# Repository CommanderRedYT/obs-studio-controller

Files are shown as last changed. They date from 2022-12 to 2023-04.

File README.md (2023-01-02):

# obs-studio-controller
DIY hardware + software to control obs studio

## What is this?
This project will be a do-it-yourself solution to control OBS Studio.

It will have a custom PCB, based on the ESP32, with rotary encoders, buttons and and optional tft display.
I am planning on having a NodeJS backend as there are already great librarys to connect to OBS Studio!
The backend will also host a website to configure the device.

I am also planning on making a Video series showing my path on creating this project.

Tl;Dr:

## Features

- [ ] Custom PCB containing digital and analog inputs, based on the Espressif 32 Microcontroller.
- [ ] A 3D printable housing for the electronics
- [ ] NodeJS backend for configuring or updating the device

More will be added after designing and testing!

## Updating
I am planning to implement Over The Air Updates as well as flashing via USB C.

The ESP32 software will be using the ESP-IDF. From experience I have noticed some usability problems, so I will be using GitHub CI to build and then host the binaries.

## Contributing
If you encounter any problems, or have improvements, feel free to open an Issue or even a Pull Request!

## "Roadmap"
- After ordering the [first version](https://github.com/CommanderRedYT/obs-studio-controller/releases/tag/ordered-01) I discovered that I accidentally selected the wrong part for the rotary encoders (ones without buttons). Next revision will have that fixed, but for now, I will need to reorder the right components and try to replace the ones on the pcb

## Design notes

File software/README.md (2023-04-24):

# Software

## Compiling the firmware
1. Make sure you fully clone this repository with `git clone --recursive git@github.com:CommanderRedYT/obs-studio-controller.git`
2. Install the esp-idf via `./esp-idf/install.sh`
3. Source the environment via `source ./export.sh` or `. .export.sh`
4. Switch to the correct build config via `switchconf.sh <config>`
5. Run `idf.py build` to build the firmware

## Information for Flashing
Because the display is connected to GPIO12, you will need to burn an efuse to set the flash voltage to 3.3V. To do this, execute `tools/dev-burn-efuse` and enter `BURN`.

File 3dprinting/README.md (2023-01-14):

# 3d printing

This is a collection of 3d printing files for the project.

## File structure
There is a folder for each tagged version of the pcb (if it is not compatible anymore). In there, there are files named **&lt;name&gt;_&lt;fusion360_version&gt;.stl**.

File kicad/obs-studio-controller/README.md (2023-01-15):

# pcb

## Version 0.1 (Routing complete)
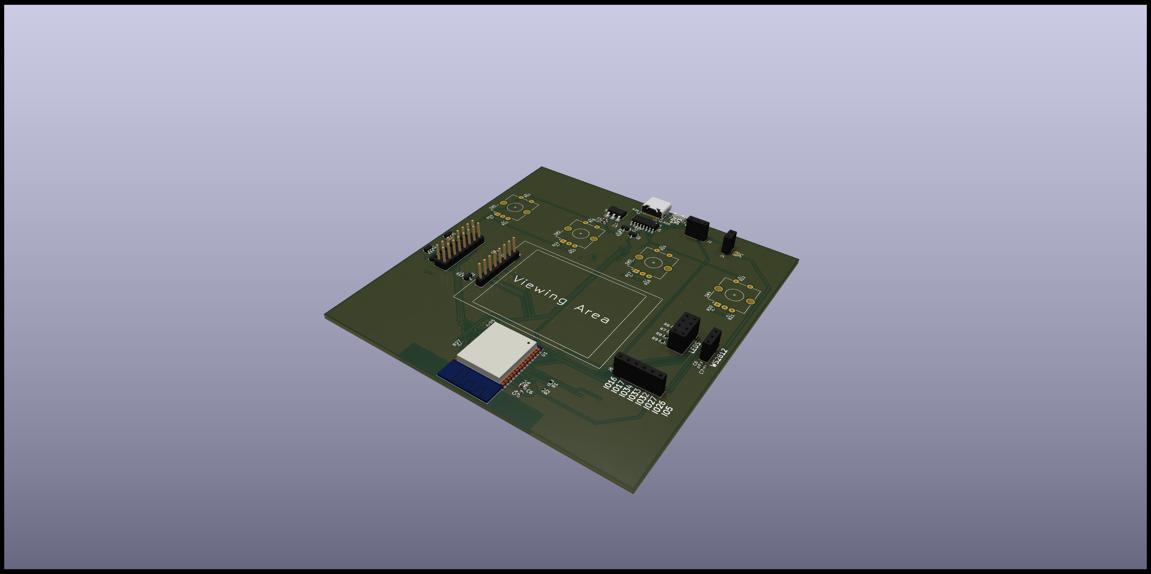
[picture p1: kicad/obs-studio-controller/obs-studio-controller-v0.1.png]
Image of version 0.1


## Version 1.0 (PCB complete)
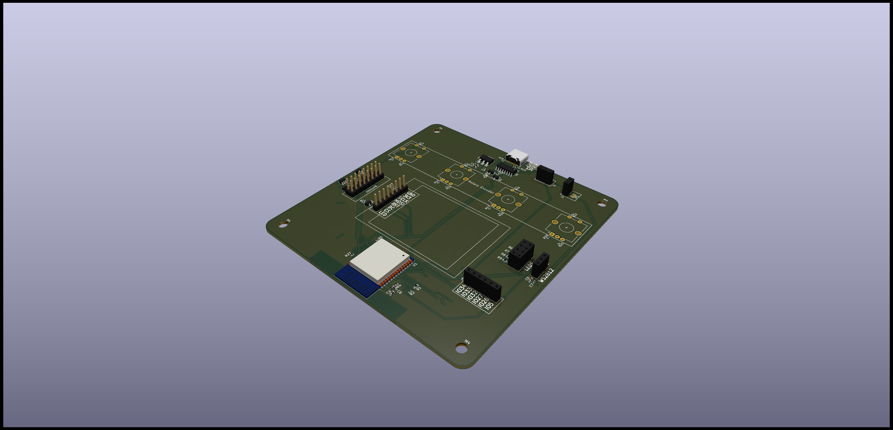
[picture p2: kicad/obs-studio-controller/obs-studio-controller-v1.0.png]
Image of version 1.0


## Version 1.1 (Fix wrong rotary encoder)
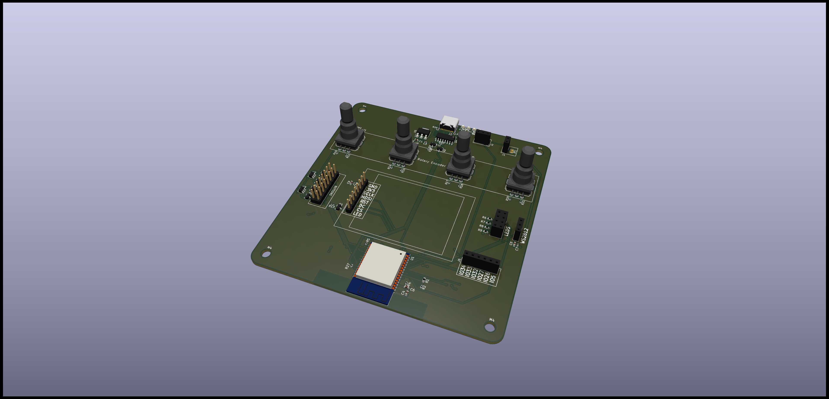
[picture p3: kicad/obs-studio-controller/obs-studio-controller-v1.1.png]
Image of version 1.1


## Version 1.2 (Fix flipped display header)
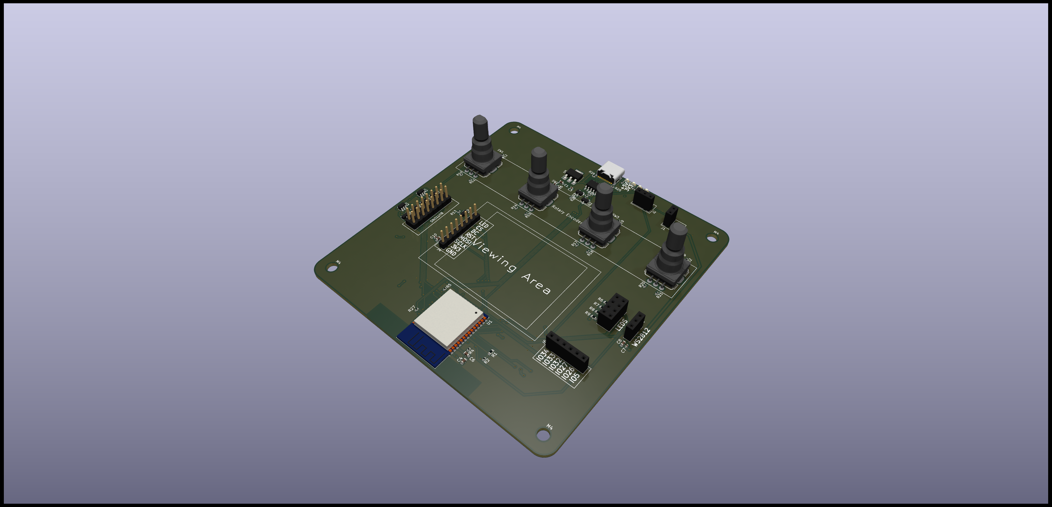
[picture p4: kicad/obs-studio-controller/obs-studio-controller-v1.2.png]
Image of version 1.2


## Version 2.0 (Actually connect the rotary encoders)
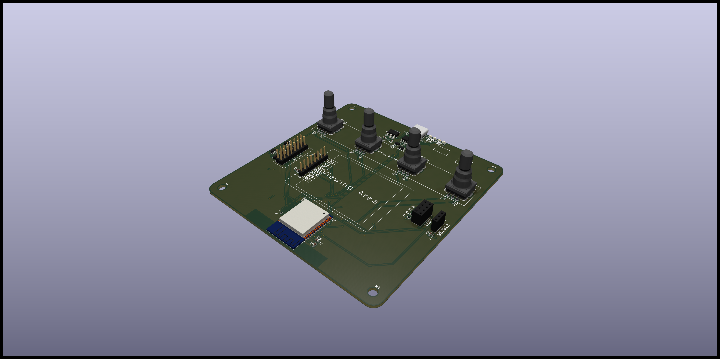
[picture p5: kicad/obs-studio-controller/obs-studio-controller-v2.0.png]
Image of version 2.0


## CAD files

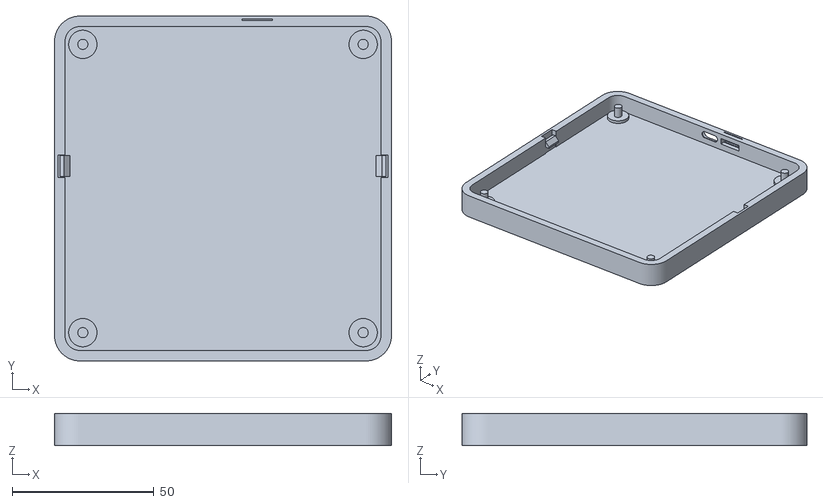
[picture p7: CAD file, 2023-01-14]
3dprinting/v1.1/case_bottom_v8.stl
119.0 x 121.8 x 11.4

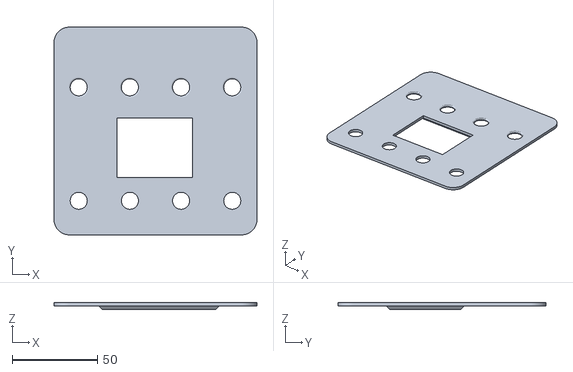
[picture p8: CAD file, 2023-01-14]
3dprinting/v1.1/case_top_v8.stl
119.0 x 121.8 x 4.00

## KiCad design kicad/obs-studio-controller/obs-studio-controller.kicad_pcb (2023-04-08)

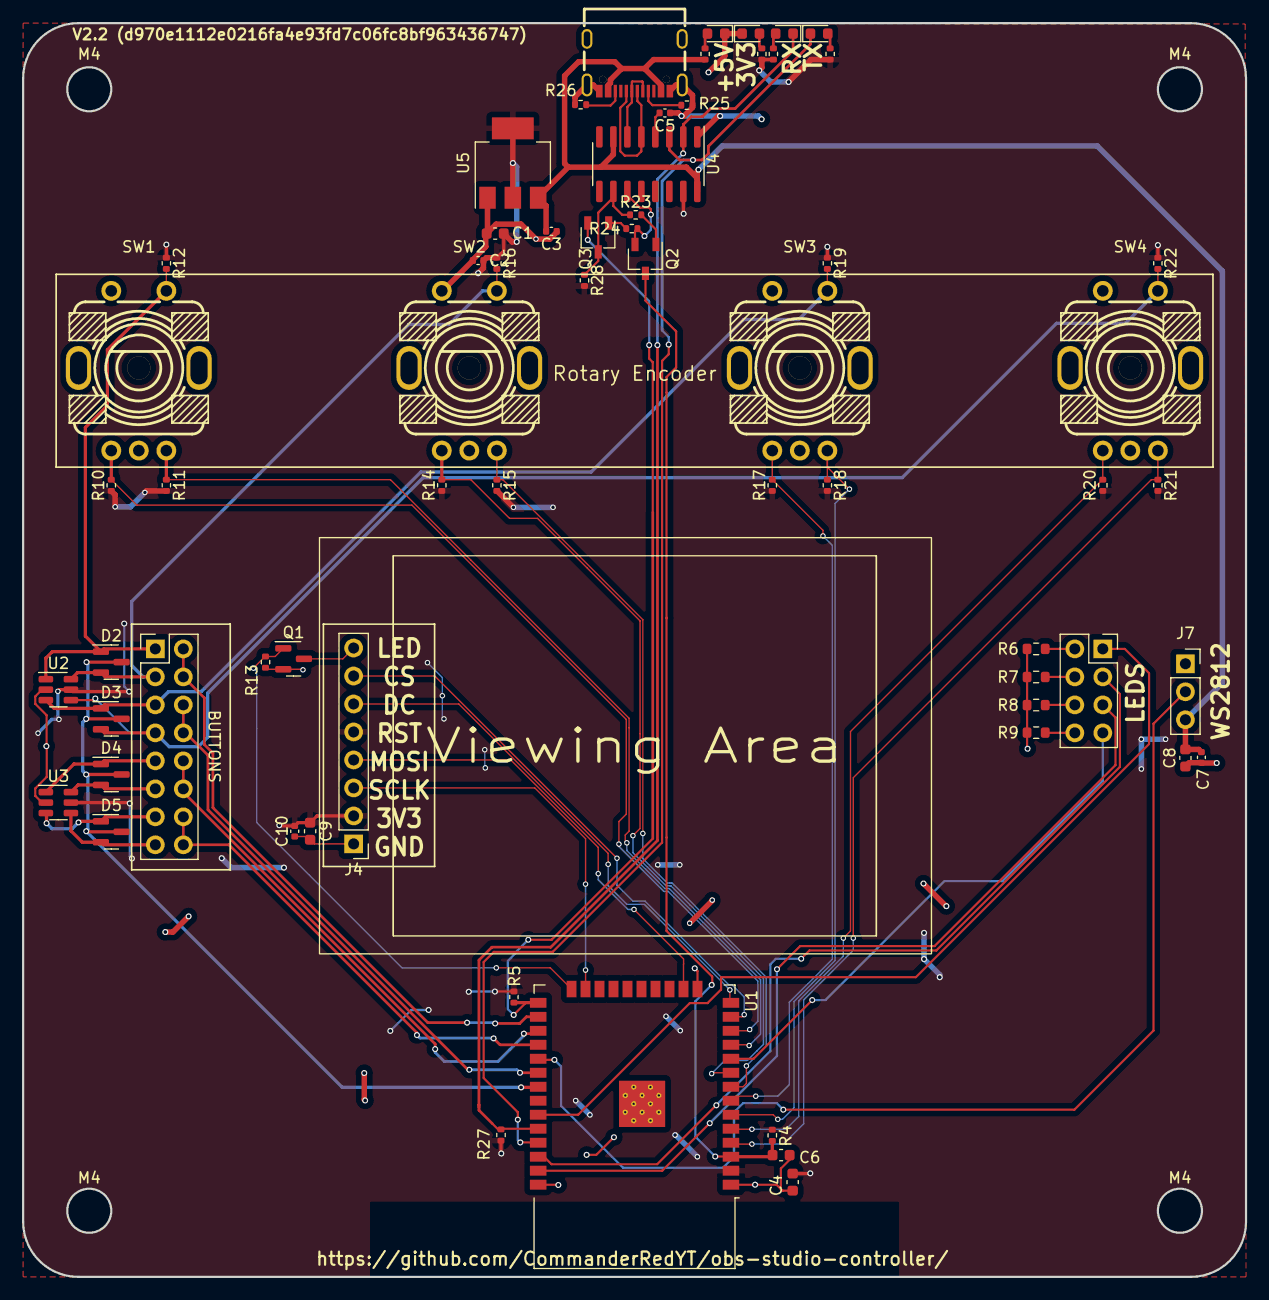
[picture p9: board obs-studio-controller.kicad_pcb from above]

Board: 2 copper layers, 111.0 x 113.8 mm, 64 parts (0 on the bottom side), 56 nets.

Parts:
C1, C6, C8, C9: 10u; C_0603_1608Metric
C2, C3, C5, C7, C10: 100n; C_0402_1005Metric
C4: 1u; C_0603_1608Metric
D2, D3, D4, D5: BAV99; SOT-23
D6, D7, D8: LED; LED_0603_1608Metric
D9: LED5V; LED_0603_1608Metric
J3: LEDS; PinSocket_2x04_P2.54mm_Vertical
J4: Conn_Display; DISPLAY
J5: BUTTONS; PinHeader_2x08_P2.54mm_Vertical
J7: WS2812; PinSocket_1x03_P2.54mm_Vertical
Q1: 2N7002; SOT-23
Q2, Q3: SS8050_C2150; TSOT-23
R4, R5, R29, R30, R31, R32: 1k; R_0402_1005Metric
R6, R7, R8, R9: 100r; R_0603_1608Metric
R10, R11, R12, R13, R14, R15, R16, R17, R18, R19, R20, R21, R22, R27, R28: 10k; R_0402_1005Metric
R23, R24: 12k; R_0402_1005Metric
R25, R26: 5k1; R_0402_1005Metric
SW1, SW2, SW3, SW4: RotaryEncoder_Switch; SW-TH_EC11K1524406
U1: ESP32-WROOM-32
U2, U3: USBLC6-4SC6; SOT-23-6
U4: CH343G; SOIC-16_3.9x9.9mm_P1.27mm
U5: AMS1117-3.3; SOT-223-3_TabPin2
USBC1: MC-311D; USB-C-SMD_MC-311D

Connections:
+3V3: C1.2, C2.2, C4.2, C9.1, C10.2, J4.2, J4.5, R4.1, R5.1, R10.1, R11.2, R12.1, R14.1, R15.2, R16.1, R17.1, R18.2, R19.1, R20.1, R21.2, R22.1, R27.2, R28.2, R29.1, R30.1, R31.1, U1.2 (VDD), U2.5 (VBUS), U3.5 (VBUS), U4.15 (VIO), U5.2 (VO)
/AMS1117-5V-3v3/5V: C3.2, C7.2, C8.2, J7.3, R32.1, U4.7 (VBUS), U4.16 (VDD5), U5.3 (VI), USBC1.A4-B9 (VBUS), USBC1.B4-A9 (VBUS)
/BTN_IN1: J5.2, J5.4, U1.26 (IO4)
/BTN_IN2: J5.6, J5.8, U1.30 (IO18)
/BTN_IN3: J5.10, J5.12, U1.27 (IO16)
/BTN_IN4: J5.14, J5.16, U1.28 (IO17)
/BTN_OUT: D2.3 (K), D3.3 (K), D4.3 (K), D5.3 (K), U1.31 (IO19)
/BUTTON_1: D2.1 (K), J5.1, R12.2, SW1.E, U2.1 (I/O1)
/BUTTON_2: D2.2 (A), J5.3, R16.2, SW2.E, U2.6 (I/O4)
/BUTTON_3: D3.1 (K), J5.5, R19.2, SW3.E, U2.3 (I/O2)
/BUTTON_4: D3.2 (A), J5.7, R22.2, SW4.E, U2.4 (I/O3)
/Buttons/BUTTON_5: D4.1 (K), J5.9, U3.1 (I/O1)
/Buttons/BUTTON_6: D4.2 (A), J5.11, U3.6 (I/O4)
/Buttons/BUTTON_7: D5.1 (K), J5.13, U3.3 (I/O2)
/Buttons/BUTTON_8: D5.2 (A), J5.15, U3.4 (I/O3)
/DISPLAY_CS: J4.7, U1.13 (IO14)
/DISPLAY_DC: J4.6, U1.14 (IO12)
/DISPLAY_LED: Q1.1 (G), R13.1, U1.24 (IO2)
/DISPLAY_MOSI: J4.4, U1.16 (IO13)
/DISPLAY_SCLK: J4.3, U1.23 (IO15)
/Flasher/DTR: Q3.3 (C), R23.1, R28.1, U4.10 (~DTR/TNOW)
/Flasher/ESP_EN: C6.2, Q2.3 (C), R4.2, U1.3 (EN)
/Flasher/ESP_IO0: Q3.2 (E), R5.2, U1.25 (IO0)
/Flasher/ESP_RX: D6.1 (K), R27.1, U1.34 (RXD0/IO3), U4.2 (TXD)
/Flasher/ESP_TX: D7.1 (K), U1.35 (TXD0/IO1), U4.3 (RXD)
/Flasher/RTS: Q2.2 (E), R24.1, U4.11 (~RTS)
/Flasher/USB_DN: U4.6 (UD-), USBC1.A7 (DN1), USBC1.B7 (DN2)
/Flasher/USB_DP: U4.5 (UD+), USBC1.A6 (DP1), USBC1.B6 (DP2)
/IO5: J7.2, U1.29 (IO5)
/ROT1_CLK: R11.1, SW1.B, U1.11 (IO26)
/ROT1_DT: R10.2, SW1.A, U1.12 (IO27)
/ROT2_CLK: R15.1, SW2.B, U1.8 (IO32)
/ROT2_DT: R14.2, SW2.A, U1.9 (IO33)
/ROT3_CLK: R18.1, SW3.B, U1.6 (IO34)
/ROT3_DT: R17.2, SW3.A, U1.7 (IO35)
/ROT4_CLK: R21.1, SW4.B, U1.4 (SENSOR_VP)
/ROT4_DT: R20.2, SW4.A, U1.5 (SENSOR_VN)
GND: C1.1, C2.1, C3.1, C4.1, C5.1, C6.1, C7.1, C8.1, C9.2, C10.1, D8.1 (K), D9.1 (K), J4.1, J7.1, Q1.2 (S), R6.1, R7.1, R8.1, R9.1, R13.2, R25.2, R26.1, SW1.C, SW1.D, SW2.C, SW2.D, SW3.C, SW3.D, SW4.C, SW4.D, U1.1 (GND), U1.15 (GND), U1.38 (GND), U1.39 (GND), U2.2 (GND), U3.2 (GND), U4.1 (GND), U5.1 (GND), USBC1.1 (SHIELD), USBC1.2 (SHIELD), USBC1.3 (SHIELD), USBC1.4 (SHIELD), USBC1.A1-B12 (GND), USBC1.B1-A12 (GND)
unnamed: C5.2, U4.4 (V3)
unnamed: D6.2 (A), R29.2
unnamed: D7.2 (A), R30.2
unnamed: D8.2 (A), R31.2
unnamed: D9.2 (A), R32.2
unnamed: J3.1, U1.33 (IO21)
unnamed: J3.2, R6.2
unnamed: J3.3, U1.36 (IO22)
unnamed: J3.4, R7.2
unnamed: J3.5, U1.37 (IO23)
unnamed: J3.6, R8.2
unnamed: J3.7, U1.10 (IO25)
unnamed: J3.8, R9.2
unnamed: J4.8, Q1.3 (D)
unnamed: Q2.1 (B), R23.2
unnamed: Q3.1 (B), R24.2
unnamed: R25.1, USBC1.A5 (CC1)
unnamed: R26.2, USBC1.B5 (CC2)

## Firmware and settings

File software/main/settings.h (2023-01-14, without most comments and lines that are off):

#pragma once
#include <array>
#include <optional>
#include <fmt/core.h>
#include <configmanager.h>
#include <configconstraints_base.h>
#include <configconstraints_espchrono.h>
#include <configwrapper.h>
#include <espchrono.h>
#include <espwifiutils.h>
#include "enums.h"
using namespace espconfig;
#ifdef BOARD_REVISION_V1
#define DEFAULT_SCREEN_FLIP true
#else
#define DEFAULT_SCREEN_FLIP false
#endif
namespace settings {
std::string defaultHostname();
enum class AllowReset { NoReset, DoReset };
constexpr auto NoReset = AllowReset::NoReset;
constexpr auto DoReset = AllowReset::DoReset;
template<typename T>
class ConfigWrapperDynamicKey : public ConfigWrapper<T>
{
    CPP_DISABLE_COPY_MOVE(ConfigWrapperDynamicKey)
    using Base = ConfigWrapper<T>;
public:
    using value_t = typename Base::value_t;
    using ConstraintCallback = typename Base::ConstraintCallback;
    ConfigWrapperDynamicKey(const char *nvsName) : m_nvsName{nvsName} {}
    const char *nvsName() const override final { return m_nvsName; }
private:
    const char * const m_nvsName;
};
class WiFiConfig
{
public:
    WiFiConfig(const char *ssidNvsKey, const char *passNvsKey,
               const char *useStaticIpKey, const char *staticIpKey, const char *staticSubnetKey, const char *staticGatewayKey,
               const char *useStaticDnsKey, const char *staticDns0Key, const char *staticDns1Key, const char *staticDns2Key) :
       ssid{ssidNvsKey},
       pass{passNvsKey},
       useStaticIp{useStaticIpKey},
       staticIp{staticIpKey},
       staticSubnet{staticSubnetKey},
       staticGateway{staticGatewayKey},
       useStaticDns{useStaticDnsKey},
       staticDns0{staticDns0Key},
       staticDns1{staticDns1Key},
       staticDns2{staticDns2Key}
    {}
    struct : ConfigWrapperDynamicKey<std::string>
    {
        using ConfigWrapperDynamicKey<std::string>::ConfigWrapperDynamicKey;
        bool allowReset() const override final { return true; }
        std::string defaultValue() const override final { return {}; }
        ConfigConstraintReturnType checkValue(value_t value) const override final { return StringMaxSize<32>(value); }
    } ssid;
    struct : ConfigWrapperDynamicKey<std::string>
    {
        using ConfigWrapperDynamicKey<std::string>::ConfigWrapperDynamicKey;
        bool allowReset() const override final { return true; }
        std::string defaultValue() const override final { return {}; }
        ConfigConstraintReturnType checkValue(value_t value) const override final { return StringMaxSize<64>(value); }
    } pass;
    struct : ConfigWrapperDynamicKey<bool>
    {
        using ConfigWrapperDynamicKey<bool>::ConfigWrapperDynamicKey;
        bool allowReset() const override final { return true; }
        bool defaultValue() const override final { return false; }
        ConfigConstraintReturnType checkValue(value_t value) const override final { return {}; }
    } useStaticIp;
    struct : ConfigWrapperDynamicKey<wifi_stack::ip_address_t>
    {
        using ConfigWrapperDynamicKey<wifi_stack::ip_address_t>::ConfigWrapperDynamicKey;
        bool allowReset() const override final { return true; }
        wifi_stack::ip_address_t defaultValue() const override final { return {}; }
        ConfigConstraintReturnType checkValue(value_t value) const override final { return {}; }
    } staticIp;
    struct : ConfigWrapperDynamicKey<wifi_stack::ip_address_t>
    {
        using ConfigWrapperDynamicKey<wifi_stack::ip_address_t>::ConfigWrapperDynamicKey;
        bool allowReset() const override final { return true; }
        wifi_stack::ip_address_t defaultValue() const override final { return {}; }
        ConfigConstraintReturnType checkValue(value_t value) const override final { return {}; }
    } staticSubnet;
    struct : ConfigWrapperDynamicKey<wifi_stack::ip_address_t>
    {
        using ConfigWrapperDynamicKey<wifi_stack::ip_address_t>::ConfigWrapperDynamicKey;
        bool allowReset() const override final { return true; }
        wifi_stack::ip_address_t defaultValue() const override final { return {}; }
        ConfigConstraintReturnType checkValue(value_t value) const override final { return {}; }
    } staticGateway;
    struct : ConfigWrapperDynamicKey<bool>
    {
        using ConfigWrapperDynamicKey<bool>::ConfigWrapperDynamicKey;
        bool allowReset() const override final { return true; }
        bool defaultValue() const override final { return false; }
        ConfigConstraintReturnType checkValue(value_t value) const override final { return {}; }
    } useStaticDns;
    struct : ConfigWrapperDynamicKey<wifi_stack::ip_address_t>
    {
        using ConfigWrapperDynamicKey<wifi_stack::ip_address_t>::ConfigWrapperDynamicKey;
        bool allowReset() const override final { return true; }
        wifi_stack::ip_address_t defaultValue() const override final { return {}; }
        ConfigConstraintReturnType checkValue(value_t value) const override final { return {}; }
    } staticDns0;
    struct : ConfigWrapperDynamicKey<wifi_stack::ip_address_t>
    {
        using ConfigWrapperDynamicKey<wifi_stack::ip_address_t>::ConfigWrapperDynamicKey;
        bool allowReset() const override final { return true; }
        wifi_stack::ip_address_t defaultValue() const override final { return {}; }
        ConfigConstraintReturnType checkValue(value_t value) const override final { return {}; }
    } staticDns1;
    struct : ConfigWrapperDynamicKey<wifi_stack::ip_address_t>
    {
        using ConfigWrapperDynamicKey<wifi_stack::ip_address_t>::ConfigWrapperDynamicKey;
        bool allowReset() const override final { return true; }
        wifi_stack::ip_address_t defaultValue() const override final { return {}; }
        ConfigConstraintReturnType checkValue(value_t value) const override final { return {}; }
    } staticDns2;
};
class ConfigContainer;
extern ConfigManager<ConfigContainer> configs;
class ConfigContainer
{
    using mac_t = wifi_stack::mac_t;
    using ip_address_t = wifi_stack::ip_address_t;
public:
    struct : ConfigWrapper<std::optional<mac_t>>
    {
        bool allowReset() const override final { return false; }
        const char *nvsName() const override final { return "baseMacAddrOver"; }
        value_t defaultValue() const override final { return std::nullopt; }
        ConfigConstraintReturnType checkValue(value_t value) const override final { return {}; }
    } baseMacAddressOverride;
    struct : ConfigWrapper<std::string>
    {
        bool allowReset() const override final { return true; }
        const char *nvsName() const override final { return "hostname"; }
        std::string defaultValue() const override final { return defaultHostname(); }
        ConfigConstraintReturnType checkValue(value_t value) const override final { return {}; }
    } hostname;
    struct : ConfigWrapper<bool>
    {
        bool allowReset() const override final { return true; }
        const char *nvsName() const override final { return "displayRot"; }
        value_t defaultValue() const override final { return DEFAULT_SCREEN_FLIP; }
        ConfigConstraintReturnType checkValue(value_t value) const override final { return {}; }
    } displayRotated;
    struct : ConfigWrapper<bool>
    {
        bool allowReset() const override final { return true; }
        const char *nvsName() const override final { return "enable_sta"; }
        value_t defaultValue() const override final { return true; }
        ConfigConstraintReturnType checkValue(value_t value) const override final { return {}; }
    } wifiStaEnabled;
    std::array<WiFiConfig, 10> wifi_configs {
        WiFiConfig{"wifi_ssid0", "wifi_pass0", "wifi_use_static_ip0", "wifi_static_ip0", "wifi_static_subnet0", "wifi_static_gateway0", "wifi_use_static_dns0", "wifi_static_dnsA0", "wifi_static_dnsB0", "wifi_static_dnsC0"},
        WiFiConfig{"wifi_ssid1", "wifi_pass1", "wifi_use_static_ip1", "wifi_static_ip1", "wifi_static_subnet1", "wifi_static_gateway1", "wifi_use_static_dns1", "wifi_static_dnsA1", "wifi_static_dnsB1", "wifi_static_dnsC1"},
        WiFiConfig{"wifi_ssid2", "wifi_pass2", "wifi_use_static_ip2", "wifi_static_ip2", "wifi_static_subnet2", "wifi_static_gateway2", "wifi_use_static_dns2", "wifi_static_dnsA2", "wifi_static_dnsB2", "wifi_static_dnsC2"},
        WiFiConfig{"wifi_ssid3", "wifi_pass3", "wifi_use_static_ip3", "wifi_static_ip3", "wifi_static_subnet3", "wifi_static_gateway3", "wifi_use_static_dns3", "wifi_static_dnsA3", "wifi_static_dnsB3", "wifi_static_dnsC3"},
        WiFiConfig{"wifi_ssid4", "wifi_pass4", "wifi_use_static_ip4", "wifi_static_ip4", "wifi_static_subnet4", "wifi_static_gateway4", "wifi_use_static_dns4", "wifi_static_dnsA4", "wifi_static_dnsB4", "wifi_static_dnsC4"},
        WiFiConfig{"wifi_ssid5", "wifi_pass5", "wifi_use_static_ip5", "wifi_static_ip5", "wifi_static_subnet5", "wifi_static_gateway5", "wifi_use_static_dns5", "wifi_static_dnsA5", "wifi_static_dnsB5", "wifi_static_dnsC5"},
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

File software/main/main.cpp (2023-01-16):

constexpr const char * const TAG = "MAIN";

// esp-idf includes
#include <esp_log.h>

// 3rdparty lib includes
#include <espchrono.h>
#include <screenmanager.h>

// local includes
#include "screens.h"
#include "screens/mainmenu.h"
#include "settings.h"
#include "taskmanager.h"

extern "C" void app_main()
{
    using namespace display;

    if (const auto result = configs.init("config"); result != ESP_OK)
        ESP_LOGE(TAG, "configs.init() failed: %s", esp_err_to_name(result));

    display::init();

    for (auto &task : schedulerTasks)
    {
        ESP_LOGI(TAG, "Starting task %s", task.name());
        setBootMsg(task.name());
        task.setup();
    }

    espgui::switchScreen<gui::MainMenu>();

    while (true)
    {
        for (auto &task : schedulerTasks)
            task.loop();

        vTaskDelay(1);
    }
}

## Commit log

2022-12-30 Added initial schematic
    [buttons.kicad_sch, display.kicad_sch, obs-studio-controller.kicad_pcb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]
2022-12-30 Placed parts in pcb layout, nothing moved yet
    [buttons.kicad_sch, display.kicad_sch, obs-studio-controller.kicad_pcb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]
2022-12-31 Routing complete
    [buttons.kicad_sch, display.kicad_sch, obs-studio-controller.kicad_pcb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]
2023-01-01 Fixed label, changed edge cuts, added screw holes
    [obs-studio-controller.kicad_pcb]
2023-01-01 Added some labels
    [obs-studio-controller.kicad_pcb]
2023-01-01 Updated production files
    [buttons.kicad_sch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]
2023-01-02 Added rotary 3d model, discovered that the lcsc part number is wrong
    [obs-studio-controller.kicad_pcb, obs-studio-controller.kicad_sch, rotary.kicad_sch]
2023-01-05 Fixed rotary encoder
    [obs-studio-controller-CuBottom.gbr, obs-studio-controller-CuTop.gbr, obs-studio-controller-EdgeCuts.gbr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]
2023-01-05 Updated paths
    [obs-studio-controller.kicad_pcb]
2023-01-05 Updated step
    [obs-studio-controller-CuBottom.gbr, obs-studio-controller-CuTop.gbr, obs-studio-controller-EdgeCuts.gbr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]
2023-01-13 Fix flipped display header
    [obs-studio-controller-CuBottom.gbr, obs-studio-controller-CuTop.gbr, obs-studio-controller-EdgeCuts.gbr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]
2023-01-14 Initial commit of firmware (Hello World working)
    [partition_table.csv]
2023-01-14 Added 3d printing files
    [case_bottom_v8.stl, case_top_v8.stl]
2023-01-14 Fixed logo, successful boot
    [partition_table.csv]
2023-01-15 Actually connect rotary encoder
    [obs-studio-controller-CuBottom.gbr, obs-studio-controller-CuTop.gbr, obs-studio-controller-EdgeCuts.gbr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]
2023-01-15 Forgot to add 3v3 trace
    [obs-studio-controller-CuBottom.gbr, obs-studio-controller-CuTop.gbr, obs-studio-controller-EdgeCuts.gbr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]
2023-04-08 Updated pcb
    [buttons.kicad_sch, display.kicad_sch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]
2023-04-08 Updated for production
    [obs-studio-controller-CuBottom.gbr, obs-studio-controller-CuTop.gbr, obs-studio-controller-EdgeCuts.gbr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]
